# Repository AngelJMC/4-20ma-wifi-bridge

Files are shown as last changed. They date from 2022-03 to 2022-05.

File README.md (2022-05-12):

# 4-20ma-wifi-bridge
IoT device to provide communication between 4-20mA sensors and cloud services. Powered by an ESP32, it allows a wireless connection via WIFI, the communication with the server is done through the MQTT protocol. The device has a user-friendly web configuration interface, which allows to manage the wifi connection, the connection with the MQTT broker as well as the calibration of the 4-20mA acquisition system. 

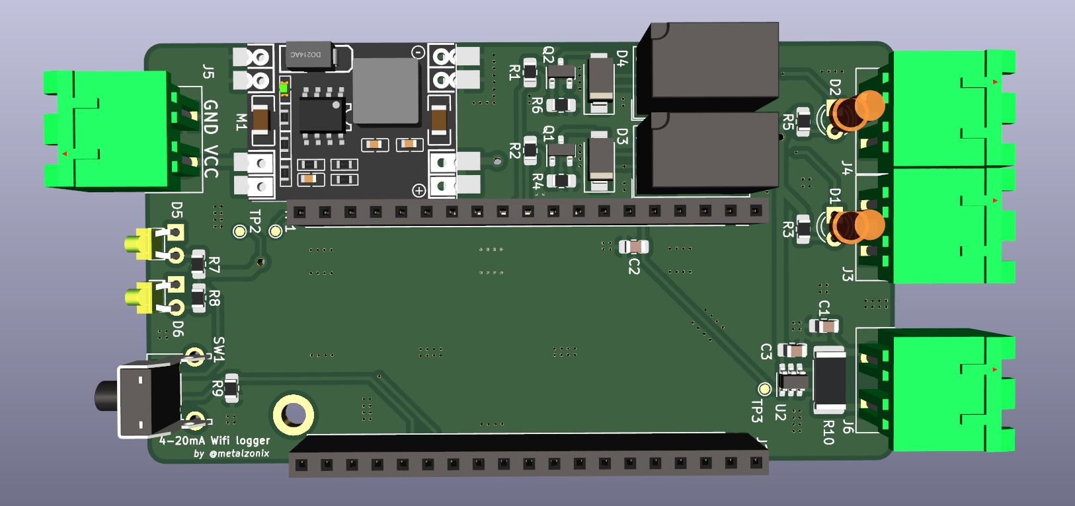
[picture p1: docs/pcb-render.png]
pcb render


## Features
### Hardware
 * 5-24v Power supply.
 * 1 Input 4-20 mA.
 * 2 Relays to control loads up to 1A at 24DVC or 0.5A at 125VAC.
 * WIFI 802.11 b/g/n (2.4 GHz), up to 150 Mbps.

## Get the source code
Download repository and update submodules:

```
$ git clone https://github.com/AngelJMC/4-20ma-wifi-bridge.git
```

### Directory Structure

    .
    ├── docs          # Documentation files
    ├── firmware      # FW source code (Visual Studio Code)
    ├── hardware      # HW design files (Kicad)

## Firmware

If you want to modify the source code or program your devices, it is highly recommended to use Visual Studio Code and the Platformio plugin. Just open the "firmware" directory with Visual Studio Code and the whole project will be ready for use.

### Load firmware 

 1. Build and Upload Filesystem Image.
 2. Build and Upload program code.

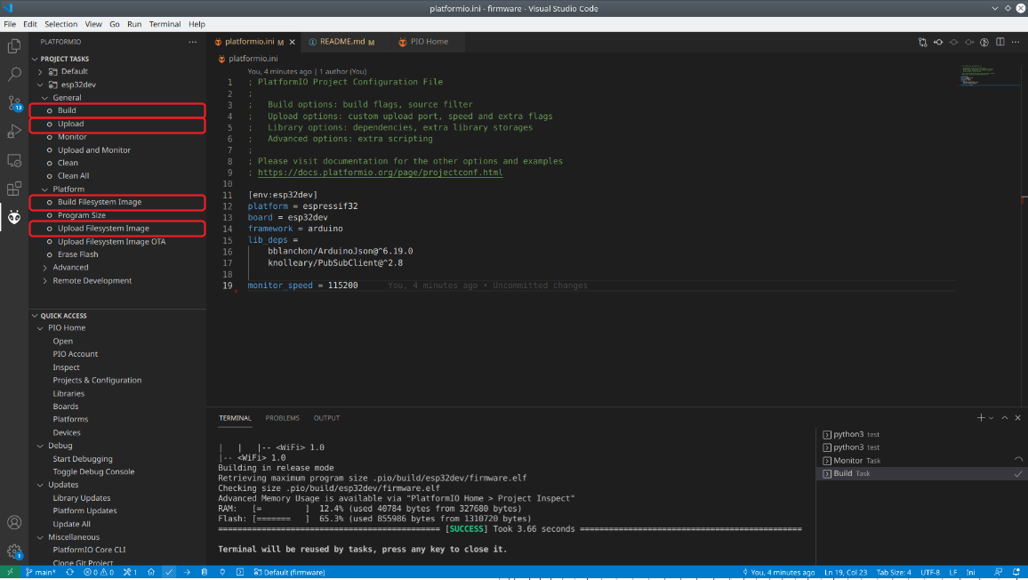
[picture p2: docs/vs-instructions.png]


## Configuration Process

 1. Build and Upload Filesystem Image to your ESP32
 2. Build and Upload program code.
 3. Connect mobile or PC with hotspot: Logger_4-20mA_XXXX. Password: Kmf5cyJUWw
 4. Go to web browser and hit 192.168.4.1. Use the credential supervisor/fEVcCQxig to enter.
 5. Go to Network section and scan for your wifi network, write password and static network configuration if you want, hit apply.
 6. Go to Service section give necessary server credential for MQTT and set the pub/sub topic names.
 7. Go to Other section if you need calibrate the 4-20mA acquisition electronic.

## Configuration Web

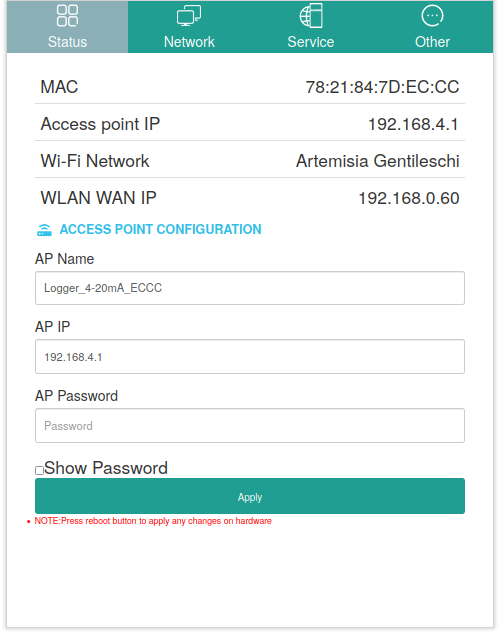
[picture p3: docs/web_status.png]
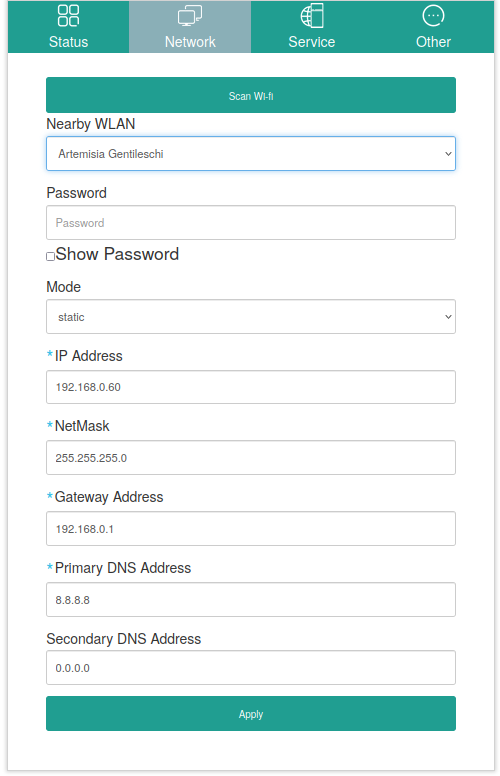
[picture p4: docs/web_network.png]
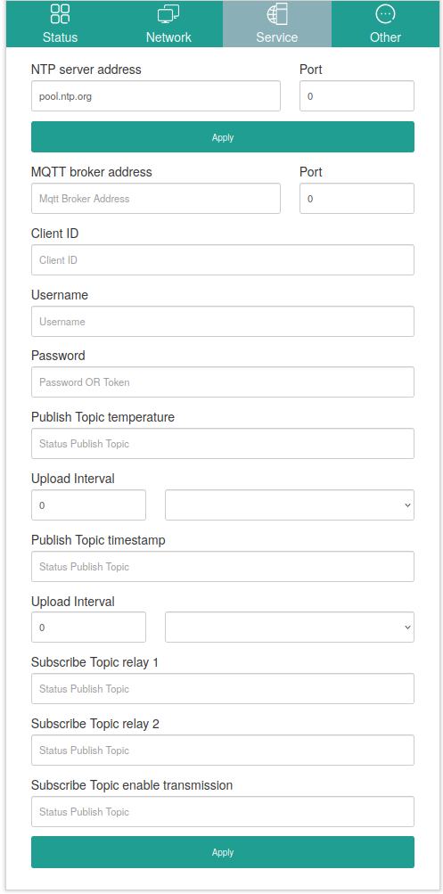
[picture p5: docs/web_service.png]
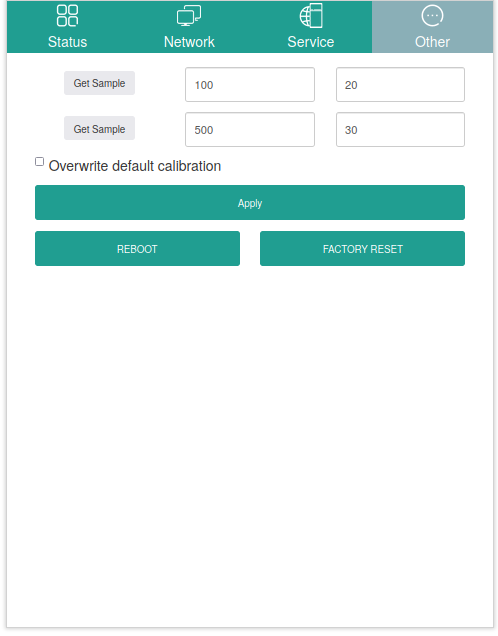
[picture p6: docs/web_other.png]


## Library Used

* ESp32_arduino :- https://github.com/espressif/arduino-esp32
* ESPAsyncWebServer:- https://github.com/me-no-dev/ESPAsyncWebServer
* AsyncTCP:- https://github.com/me-no-dev/AsyncTCP
* esp32 SPIFF File system :- https://github.com/me-no-dev/arduino-esp32fs-plugin

The configuration web page is based on the work of @futechiot https://github.com/futechiot/Configuration-webpage-esp32

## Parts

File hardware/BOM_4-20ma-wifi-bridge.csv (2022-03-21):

Id | Designator | Quantity | Supplier and ref | Value | Package
1 | R10 | 1 | ERJ1TRQF2R7U | 2.7ohm | R_2512_6332Metric_Pad1.40x3.35mm_HandSolder
2 | R5,R3,R1,R2,R7,R8 | 6 | ERJ6GEYJ102V | 1k | R_0805_2012Metric_Pad1.20x1.40mm_HandSolder
3 | R6,R4,R9 | 3 | ERJ6GEY J103V | 10k | R_0805_2012Metric_Pad1.20x1.40mm_HandSolder
4 | C1,C2 | 2 | CL21B106KPQNNNE | 10 uF | C_0805_2012Metric_Pad1.18x1.45mm_HandSolder
5 | C3 | 1 | CL21B104KCFNNNE | 100 nF | C_0805_2012Metric_Pad1.18x1.45mm_HandSolder
6 | D5 | 1 | L-204SRD | LED RED | LED_D1.8mm_W1.8mm_H2.4mm_Horizontal_O1.27mm_Z1.6mm
7 | D6 | 1 | L-204GD | LED GREEN | LED_D1.8mm_W1.8mm_H2.4mm_Horizontal_O1.27mm_Z1.6mm
8 | D2,D1 | 2 | 204-10SURD/S530-A3-L | LED | LED_D3.0mm_FlatTop
9 | D4,D3 | 2 | 1N4004 | 1N4004 | D_SMA
10 | Q2,Q1 | 2 | 2N7002E | 2N7002E | SOT-23
11 | U1 | 1 | ESP32-WROOM-32U | ESP32-DevKitC V4 | MODULE_ESP32-DEVKITC-32U
12 | U2 | 1 | LMP8640MK-F/NOPB | LMP8640 | SOT-23-6
13 | K2,K1 | 2 | G5V-1-DC5 | G5V-1 | Relay_SPDT_Omron_G5V-1
14 | J2,J1 | 2 | C319202 | Conn_01x19_Female | PinSocket_1x19_P2.54mm_Vertical
15 | J4,J3,J5,J6 | 4 | KF2EDGRC-5.0-2P | KF2EDGRC-5.0-2P | TerminalBlock__1x02_P5.00mm_90Degree
16 | J4,J3,J5,J6 | 4 | KF2EDGK-5.0-2P | KF2EDGK-5.0-2P | TerminalBlock__1x02_P5.00mm_90Degree Female
17 | SW1 | 1 | PTS645VH582LFS | SW_DIP_x01 | SW_Tactile_SPST_Angled_PTS645Vx58-2LFS
18 | M1 | 1 |  | DC-DC_Buck_Step_Module-dc-dc_module | DC-DC_Buck_Step_Module
19 |  | 1 |  | Antena WiFi de 2,4 GHz y 3dBi, | Antena WiFi de 2,4 GHz y 3dBi,

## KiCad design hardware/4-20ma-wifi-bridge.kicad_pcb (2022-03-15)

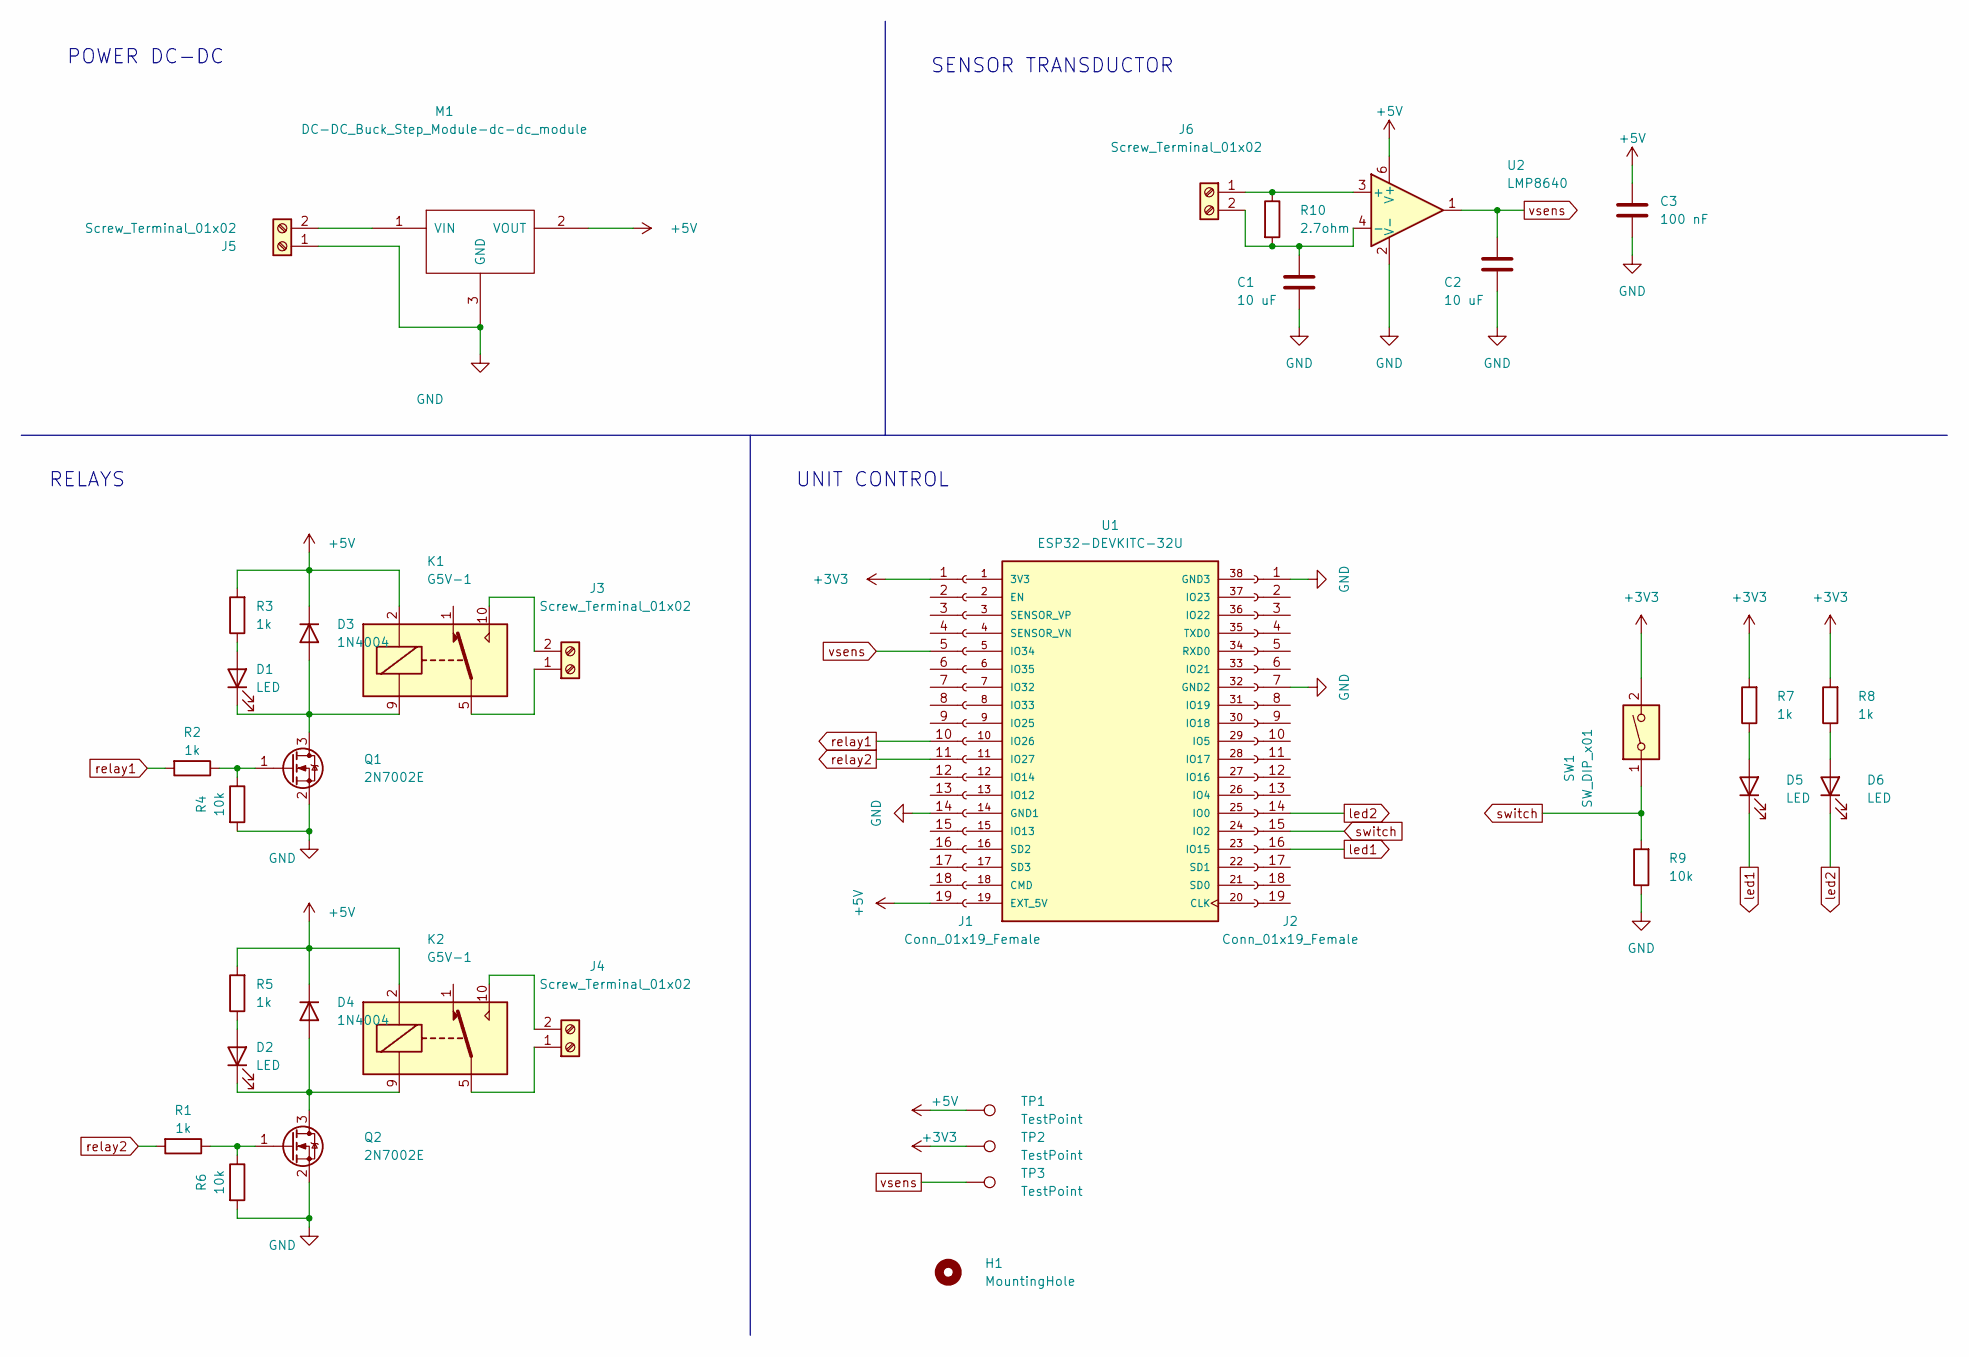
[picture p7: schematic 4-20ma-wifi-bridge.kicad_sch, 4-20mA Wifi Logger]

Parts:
C1, C2: 10 uF; C_0805_2012Metric_Pad1.18x1.45mm_HandSolder
C3: 100 nF; C_0805_2012Metric_Pad1.18x1.45mm_HandSolder
D1, D2: LED; LED_D3.0mm_FlatTop
D3, D4: 1N4004; D_SMA
D5, D6: LED; LED_D1.8mm_W1.8mm_H2.4mm_Horizontal_O1.27mm_Z1.6mm
H1: MountingHole; MountingHole_2.7mm_M2.5_ISO7380_Pad
J1, J2: Conn_01x19_Female; PinSocket_1x19_P2.54mm_Vertical
J3, J4, J5, J6: Screw_Terminal_01x02; TerminalBlock__1x02_P5.00mm_90Degree
K1, K2: G5V-1; Relay_SPDT_Omron_G5V-1
M1: DC-DC_Buck_Step_Module-dc-dc_module; DC-DC_Buck_Step_Module
Q1, Q2: 2N7002E; SOT-23
R1, R2, R3, R5, R7, R8: 1k; R_0805_2012Metric_Pad1.20x1.40mm_HandSolder
R4, R6, R9: 10k; R_0805_2012Metric_Pad1.20x1.40mm_HandSolder
R10: 2.7ohm; R_2512_6332Metric_Pad1.40x3.35mm_HandSolder
SW1: SW_DIP_x01; SW_Tactile_SPST_Angled_PTS645Vx58-2LFS
TP1, TP2, TP3: TestPoint; TestPoint_Pad_D1.0mm
U1: ESP32-DEVKITC-32U; MODULE_ESP32-DEVKITC-32U; PARTREV N/A
U2: LMP8640; SOT-23-6

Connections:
+3V3: J1.1, R7.2, R8.2, SW1.2, TP2.1
+5V: C3.1, D3.1 (K), D4.1 (K), J1.19, K1.2, K2.2, M1.2 (VOUT), R3.2, R5.2, TP1.1, U2.6 (V+)
GND: C1.2, C2.2, C3.2, J1.14, J2.1, J2.7, J5.1, M1.3 (GND), Q1.2 (S), Q2.2 (S), R4.2, R6.2, R9.1, U2.2 (V-)
unnamed: C1.1, J6.2, R10.2, U2.4 (-)
unnamed: D1.1 (K), D3.2 (A), K1.9, Q1.3 (D)
unnamed: D1.2 (A), R3.1
unnamed: D2.1 (K), D4.2 (A), K2.9, Q2.3 (D)
unnamed: D2.2 (A), R5.1
unnamed: D5.2 (A), R7.1
unnamed: D6.2 (A), R8.1
unnamed: J3.1, K1.5, K1.6
unnamed: J3.2, K1.10
unnamed: J4.1, K2.5, K2.6
unnamed: J4.2, K2.10
unnamed: J5.2, M1.1 (VIN)
unnamed: J6.1, R10.1, U2.3 (+)
unnamed: Q1.1 (G), R2.1, R4.1
unnamed: Q2.1 (G), R1.1, R6.1
led1: D5.1 (K), J2.16
led2: D6.1 (K), J2.14
relay1: J1.10, R2.2
relay2: J1.11, R1.2
switch: J2.15, R9.2, SW1.1
vsens: C2.1, J1.5, TP3.1, U2.1

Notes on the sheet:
RELAYS
UNIT CONTROL
SENSOR TRANSDUCTOR
POWER DC-DC

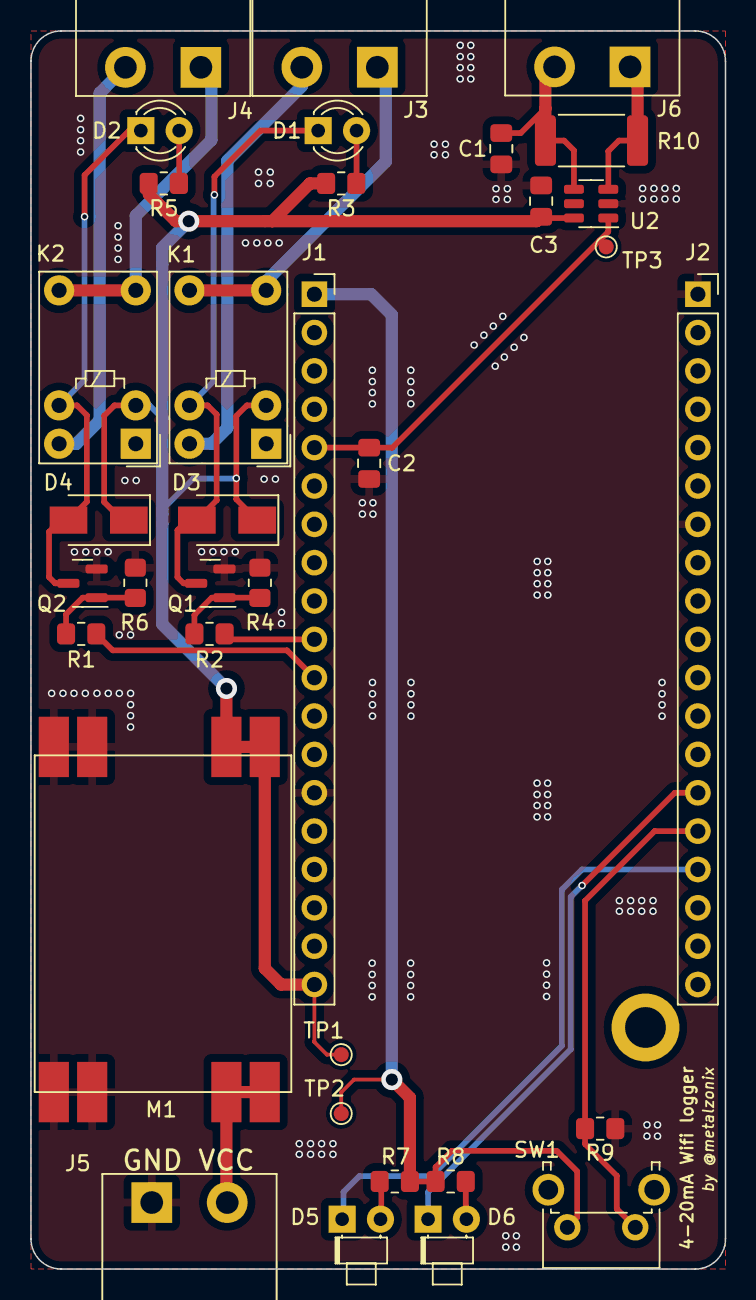
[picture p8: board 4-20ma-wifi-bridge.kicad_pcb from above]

Board: 2 copper layers, 46.0 x 82.0 mm, 36 parts (0 on the bottom side), 24 nets.

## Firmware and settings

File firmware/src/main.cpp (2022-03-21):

/*
    Project: <https://github.com/AngelJMC/4-20ma-wifi-bridge>   
    Copyright (c) 2022 Angel Maldonado <angelgesus@gmail.com>. 
    Licensed under the MIT License: <http://opensource.org/licenses/MIT>.
    SPDX-License-Identifier: MIT 
*/

#include "Arduino.h"
#include "FreeRTOS.h"
#include "webserver.h"
#include "mqtt_task.h"
#include "config-mng.h"
#include "SPIFFS.h"
#include <ArduinoJson.h>
#include "uinterface.h"

#define CONFIG_ASYNC_TCP_RUNNING_CORE 

static TimerHandle_t tmswitch;

static int timerstate = 0;


static void switch_callback( TimerHandle_t xTimer ) {
    BaseType_t xHigherPriorityTaskWoken = pdFALSE;
    if (timerstate == 0) {
        if( digitalRead( SWITCH ) == LOW ) {
            if( xTimerStopFromISR( tmswitch, &xHigherPriorityTaskWoken ) != pdPASS ) {
                /* The stop command was not executed successfully.  Take appropriate
                action here. */
            }
            /*Toggle configuration mode*/
            ctrl_isConfigModeEnable() ? ctrl_exitConfigMode( ) : ctrl_enterConfigMode( );
        } 
        else {
            if( xTimerChangePeriodFromISR( tmswitch,
                                        pdMS_TO_TICKS( 4000 ),
                                        &xHigherPriorityTaskWoken ) != pdPASS ){
            /* The command to change the timers period was not executed
            successfully.  Take appropriate action here. */
            } 
            timerstate = 1;
        }
    } 
    else {
        if( xTimerStopFromISR( tmswitch, &xHigherPriorityTaskWoken ) != pdPASS ) {
            /* The stop command was not executed successfully.  Take appropriate
            action here. */
        }
        if( digitalRead( SWITCH ) == HIGH) {
            factoryreset( );
        }
    }
}


void Ext_INT1_ISR( void ) {

    BaseType_t xHigherPriorityTaskWoken = pdFALSE;
    if( xTimerChangePeriodFromISR( tmswitch,
                                   pdMS_TO_TICKS( 1000 ),
                                   &xHigherPriorityTaskWoken ) != pdPASS ){
        /* The command to change the timers period was not executed
        successfully.  Take appropriate action here. */
    } 
    
    if( xTimerStartFromISR( tmswitch, &xHigherPriorityTaskWoken ) != pdPASS ) {
        /* The start command was not executed successfully.  Take appropriate
        action here. */
    }

    timerstate = 0;
}



void setup() {
    //vTaskDelay(pdMS_TO_TICKS(1000));
    Serial.begin(115200);
    
    pinMode(LED1, OUTPUT);
    pinMode(LED2, OUTPUT);
    pinMode(RELAY1, OUTPUT);
    pinMode(RELAY2, OUTPUT);
    pinMode(SWITCH, INPUT);

    digitalWrite(LED1, LED_OFF);
    digitalWrite(LED2, LED_OFF);
    digitalWrite(RELAY1, LOW);
    digitalWrite(RELAY2, LOW);

    attachInterrupt(SWITCH, Ext_INT1_ISR, RISING);
    config_load(  );

    //########################  reading config file ########################################
    if (!SPIFFS.begin()) {
        Serial.println("An Error has occurred while mounting SPIFFS");
        return;
    }
    
    tmswitch = xTimerCreate( "tmSwitch",   pdMS_TO_TICKS( 250 ), pdTRUE, NULL, switch_callback );
    interface_init( );
    // Now set up two Tasks to run independently.
    xTaskCreate( webserver_task , "webserver-task",  1024*10  ,NULL  ,  3,  NULL );
    xTaskCreate( ctrl_task ,      "ctrl-task",       1024*3   ,NULL  ,  1,  NULL );

}


void loop() { 

}

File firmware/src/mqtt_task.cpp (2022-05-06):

/*
    Project: <https://github.com/AngelJMC/4-20ma-wifi-bridge>   
    Copyright (c) 2022 Angel Maldonado <angelgesus@gmail.com>. 
    Licensed under the MIT License: <http://opensource.org/licenses/MIT>.
    SPDX-License-Identifier: MIT 
*/

#include <WiFi.h>
#include "SPIFFS.h"
#include "ESPAsyncWebServer.h"
#include <ArduinoJson.h>
#include <PubSubClient.h>
#include <HTTPClient.h>
#include "webserver.h"
#include "config-mng.h"
#include "mqtt_task.h"
#include "time.h"
#include "uinterface.h"

enum {
    verbose = 1,
    apAutoStart = 0
};

/*Calibration equation*/
struct caleq {
    double m;
    double b;
};

WiFiClient wifiClient;
PubSubClient client(wifiClient);

/*Create a static freertos timer*/
static TimerHandle_t tmTemp;
static TimerHandle_t tmPing;
static bool isServerActive = false;

/* Declare a variable to hold the created event group. */
static EventGroupHandle_t events;
static struct service_config scfg;
static struct caleq eq = { .m = 1.0, .b = 0.0 };

static struct ctrl_status {
    int relay1 = LOW;
    int relay2 = LOW;
    int enableTemp = false;
} ctrlStatus;

char jsonstatus[128];

enum flags {
    START_AP_WIFI = 1 << 0,
    CONNECT_WIFI  = 1 << 1,
    CONNECT_MQTT  = 1 << 2
};

/*Print local time and date, used for debugging purposes*/
static void printLocalTime(){
    struct tm timeinfo;
    if(!getLocalTime(&timeinfo)){
        Serial.println("Failed to obtain time");
        return;
    }

    if( 1 < verbose ) {
        Serial.println(&timeinfo, "%A, %B %d %Y %H:%M:%S");
        Serial.print("Day of week: ");
        Serial.println(&timeinfo, "%A");
        Serial.print("Month: ");
        Serial.println(&timeinfo, "%B");
        Serial.print("Day of Month: ");
        Serial.println(&timeinfo, "%d");
        Serial.print("Year: ");
        Serial.println(&timeinfo, "%Y");
        Serial.print("Hour: ");
        Serial.println(&timeinfo, "%H");
        Serial.print("Hour (12 hour format): ");
        Serial.println(&timeinfo, "%I");
        Serial.print("Minute: ");
        Serial.println(&timeinfo, "%M");
        Serial.print("Second: ");
        Serial.println(&timeinfo, "%S");

        Serial.println("Time variables");
        char timeHour[3];
        strftime(timeHour,3, "%H", &timeinfo);
        Serial.println(timeHour);
        char timeWeekDay[10];
        strftime(timeWeekDay,10, "%A", &timeinfo);
        Serial.println(timeWeekDay);
        Serial.println();
    }
}

/*Print access point configuration*/
static void print_APcfg( struct ap_config const* ap ) {
    String myIP = WiFi.softAPIP().toString();
    Serial.printf("Set up access point. SSID: %s, PASS: %s\n", ap->ssid, ap->pass);
    Serial.printf("#### SERVER STARTED ON THIS: %s ###\n", myIP.c_str());
    printIp( "Access point ADDRESS: ", &ap->addr );
}


/*Calculate the equation of a straight line used to calibrate*/
static void getCalibrationEquation( struct caleq* eq, double x0, double y0, double x1, double y1 ) {
    double num = 0 == (x1 - x0 ) ? 1 : (x1 - x0 );
    eq->m = (y1 - y0) / num;
    eq->b = y0 - eq->m * x0;
    if( verbose ) {
        Serial.printf("Calibration equation: y = %.2f * x %c%.2f\n", eq->m, eq->b > 0.0 ? '+' : ' ', eq->b);
    }
}

/*Apply the calibration funtion to an input value.*/
static double applyCalibration( struct caleq* eq, double x ) {
    return eq->m * (x-5) + eq->b ;
} 

/*Format json string with status info.*/
static void status2json( char* json ) {
    int16_t raw = getadcValue( );
    double converted = applyCalibration( &eq, raw );
    time_t now;
    time(&now);
    sprintf(json,
    "{ \"%s\": %ld, \"%s\": %d, \"%s\": %0.1f, \"%s\": \"%s\", \"%s\": \"%s\", \"%s\": \"%s\" }",
         "timestamp", now,  
         "raw", raw,
         "temperatura", converted + 0.05, 
         "rele1", ctrlStatus.relay1 ? "ON" : "OFF", 
         "rele2", ctrlStatus.relay2 ? "ON" : "OFF",
         "transmitir", ctrlStatus.enableTemp ? "ON" : "OFF"  );
}

/*Callback function used to pusblish temperature on the mqtt topic*/
static void tmtemp_callback( TimerHandle_t xTimer ) {
    struct service_config const* sc = &scfg;
    status2json( jsonstatus );
    client.publish( sc->temp.topic, jsonstatus);
    Serial.printf("Publishing temperature %s\n", jsonstatus);          
}

/*Callback function used to pusblish timestamp on the mqtt topic*/
static void tmping_callback( TimerHandle_t xTimer ) {
    struct service_config const* sc = &scfg;
    status2json( jsonstatus );
    client.publish( sc->ping.topic, jsonstatus );
    Serial.printf("Publishing timestamp %s\n", jsonstatus);
    
    if( verbose ) {
        printLocalTime();
    }
}


/*Funtion to convert byte* to char* */
static void byteToChar(char* dest, byte* src, int len) {
    for (int i = 0; i < len; i++) {
        dest[i] = src[i];
    }
    dest[len] = '\0';
}

/*Callback function used to process messages received from subscribed mqtt topics*/
static void subs_callback(char* topic, byte *payload, unsigned int length) {

    char value[length+1];
    byteToChar(value, payload, length);
    if( verbose )
        Serial.printf("Topic: %s, value: %s\n", topic, value);
    
    struct service_config const* sc = &scfg;
    if( strcmp(sc->relay1.topic , topic) == 0 ) { 
        if ( strcmp( value, "ON") == 0 ){
            ctrlStatus.relay1 = HIGH;
            digitalWrite(RELAY1, ctrlStatus.relay1);
        }
        else if ( strcmp( value, "OFF") == 0 ) {
            ctrlStatus.relay1 = LOW;
            digitalWrite(RELAY1, ctrlStatus.relay1);
        }
        else
            Serial.printf("Invalid value for topic %s: %s\n", topic, value);
    }
    else if( strcmp(sc->relay2.topic, topic) == 0 ) {
        if ( strcmp( value, "ON") == 0 ) {
            ctrlStatus.relay2 = HIGH;
            digitalWrite(RELAY2, ctrlStatus.relay2);
        }
        else if ( strcmp( value, "OFF") == 0 ) {
            ctrlStatus.relay2 = LOW;
            digitalWrite(RELAY2, ctrlStatus.relay2);
        }
        else
            Serial.printf("Invalid value for topic %s: %s\n", topic, value);
    }
    else if( strcmp(sc->enableTemp.topic, topic) == 0 ) {
        if ( strcmp( value, "ON") == 0 ) {
            xTimerStart(tmTemp, 100 );
            ctrlStatus.enableTemp = true;
        }
        else if ( strcmp( value, "OFF") == 0 ) {
            xTimerStop(tmTemp, 100 );
            ctrlStatus.enableTemp = false;
        }
        else
            Serial.printf("Invalid value for topic %s: %s\n", topic, value);
    }
    else{
        Serial.printf("Unknown topic: %s\n", topic );
        return;
    }

    /*Publish the new status*/
    status2json( jsonstatus );
    client.publish( sc->ping.topic, jsonstatus );
}
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

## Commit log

2021-12-26 Wokr around pcb design
    [4-20ma-wifi-bridge.kicad_pcb, 4-20ma-wifi-bridge.kicad_sch]
2022-01-18 Added kicad design files
    [4-20ma-wifi-bridge.kicad_pcb, 4-20ma-wifi-bridge.kicad_sch]
2022-02-06 Added NTP configuration from webserver. Improved error checking
    [config-mng.cpp, main.cpp, mqtt_task.cpp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]
2022-02-06 Publish timestamp and adc reading
2022-02-13 Improved stability when loading the configuration website
    [config-mng.cpp, main.cpp, mqtt_task.cpp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]
2022-02-19 Implementation of led control and switch to enter in configuration mode.
2022-02-20 Implemented feature to calibrate sensor from the web pannel.
2022-03-03 Fixed bug related to the static network configuration. Encode URI component
    [config-mng.cpp, main.cpp, mqtt_task.cpp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]
2022-03-04 Improve calibration default config
2022-03-13 Fix minor bug and improve documentation
    [config-mng.cpp, main.cpp, mqtt_task.cpp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]
2022-03-13 Minor changes, bug fixing related to the mac address byte intepretation.
    [config-mng.cpp, webserver.cpp]
2022-03-15 Updated schematic and board to fix some erros
    [4-20ma-wifi-bridge.kicad_pcb, 4-20ma-wifi-bridge.kicad_sch]
2022-03-21 Added BOM and other vs project files
    [BOM_4-20ma-wifi-bridge.csv]
2022-05-05 Changed configuration mode and AP behaviour
    Now only enable/disable access point and web when the user press the
    config button.
2022-05-05 Check MQTT connection status, attempt to reconnect if there is a problem.
    [mqtt_task.cpp]
2022-05-06 Fix minor issue related to configuration mode
    [mqtt_task.cpp, webserver.cpp]
